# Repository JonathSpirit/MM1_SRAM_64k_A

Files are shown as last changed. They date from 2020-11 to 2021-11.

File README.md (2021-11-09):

# MM1_SRAM_64k_A

Copyright (C) 2020 Guillaume Guillet\
Licensed under CERN-OHL-W v2 or later

<table border="0px">
<tr>
<td>
This source describes Open Hardware and is licensed under the CERN-OHL-W v2 or later.
</td>
</tr>
<tr>
<td>
You may redistribute and modify this documentation and make products
using it under the terms of the CERN-OHL-W v2 (https:/cern.ch/cern-ohl).
This documentation is distributed WITHOUT ANY EXPRESS OR IMPLIED
WARRANTY, INCLUDING OF MERCHANTABILITY, SATISFACTORY QUALITY
AND FITNESS FOR A PARTICULAR PURPOSE. Please see the CERN-OHL-W v2
for applicable conditions.
</td>
</tr>
</table>

Made with [Kicad](https://kicad.org/)

## Description
A SRAM card with 64kBytes of capacity and compatible with [MM1 standard](https://github.com/JonathSpirit/GComputer_standard).

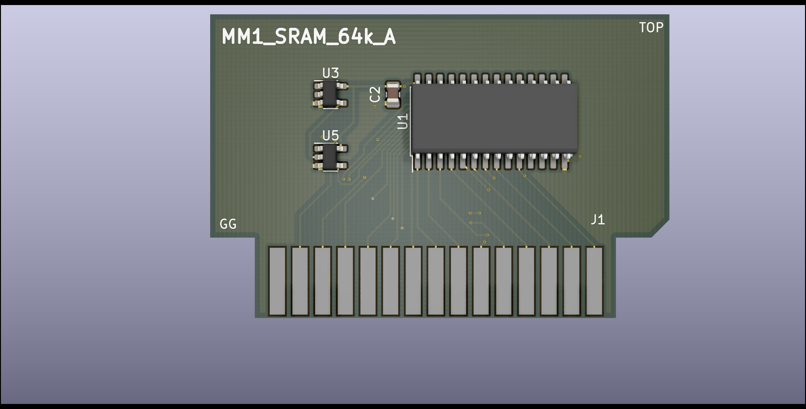
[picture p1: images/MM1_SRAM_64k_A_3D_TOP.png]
MM1_SRAM_64k_A_3D_TOP_image
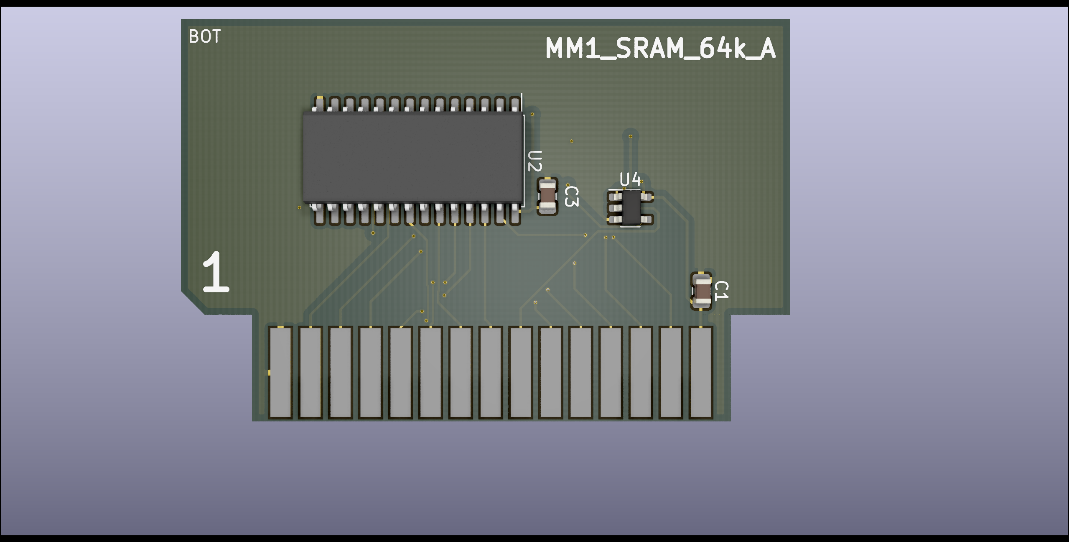
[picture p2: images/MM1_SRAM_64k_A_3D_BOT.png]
MM1_SRAM_64k_A_3D_BOT_image
 

## Status

Version :
> MM1_SRAM_64k_A revision 1

Status :
> Not tested !

Known issues :
> (Empty)

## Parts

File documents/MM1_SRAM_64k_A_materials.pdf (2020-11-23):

1

MM1_SRAM_64k_A_materials.fods

MM1_SRAM_64k_A | R1
Author : Guillaume Guillet | Revision 1 | Licensed under CERN-OHL-W v2 or later
Type | Value | Q | References | Package | Manufacturer | Store | Store ID | Unit price* | Price
C | 100nF | 3 | C1 to C3 | C_0805_2012Metric | KEMET | Mouser | 80-C0805C104K3R | 0.219 | 0.657
U | IS61LV256AL-10JL | 2 | U1, U2 | SOJ-28_P1.27mm | ISSI | Mouser | 870-61LV256AL10JLITR | 1.07 | 2.14
| 74AHC1G32 | 2 | U4, U5 | SOT-23-5 | Texas Instruments | Mouser | 595-SN74AHC1G32DBVR | 0.266 | 0.532
| 74AHC1G04 | 1 | U3 | SOT-23-5 | Texas Instruments | Mouser | 595-SN74AHC1G04DBVR | 0.266 | 0.266
- | PCB | 1 | | | G.Guillet | - | | | 0
Total price : | 3.595
*Depend of the quantity | Price is in CHF

# Project :

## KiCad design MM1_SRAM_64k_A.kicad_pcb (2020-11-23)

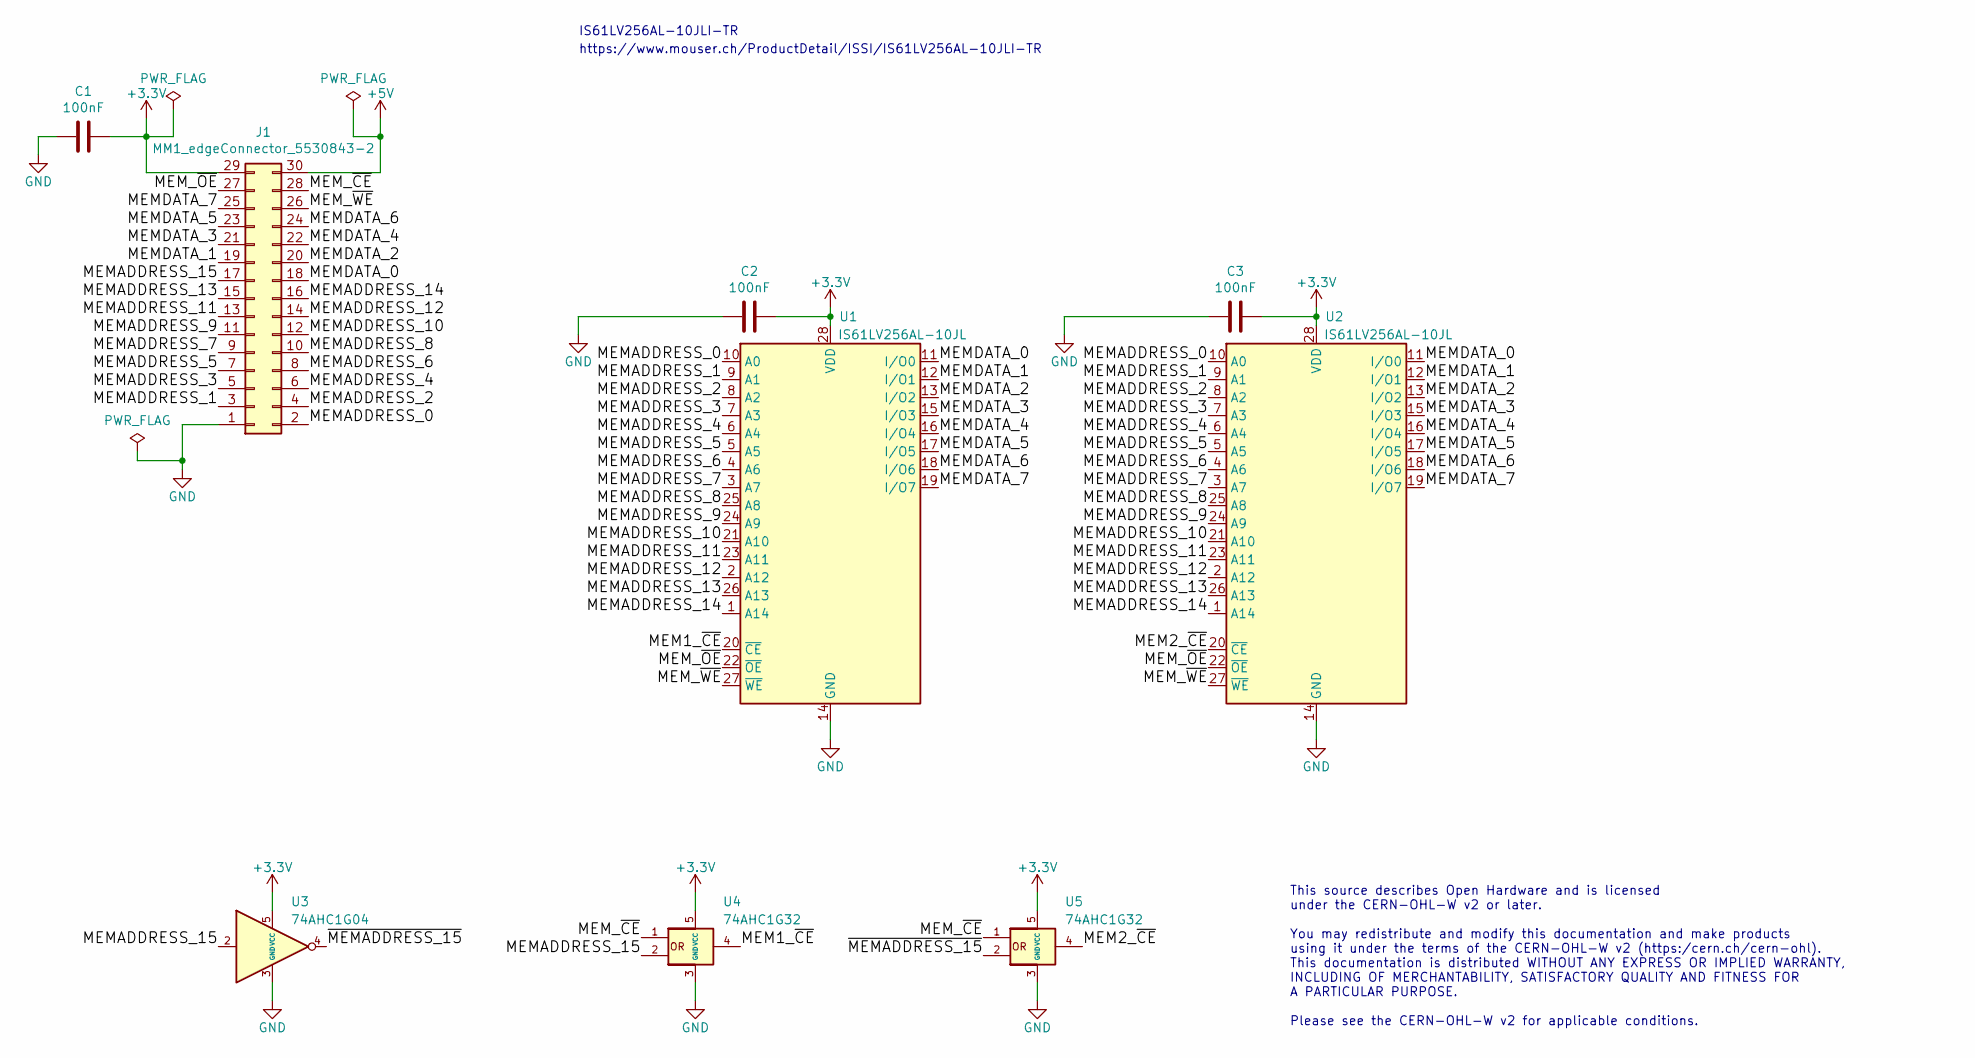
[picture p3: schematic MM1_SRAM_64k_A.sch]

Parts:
C1, C2, C3: 100nF; C_0805_2012Metric
J1: MM1_edgeConnector_5530843-2; 5530843-2_edge
U1, U2: IS61LV256AL-10JL; SOJ-28_P1.27mm
U3: 74AHC1G04; SOT-23-5
U4, U5: 74AHC1G32; SOT-23-5

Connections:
+3V3: C1.2, C2.1, C3.1, J1.29, U1.28 (VDD), U2.28 (VDD), U3.5 (VCC), U4.5 (VCC), U5.5 (VCC)
+5V: J1.30
/MEM1_~CE: U1.20 (~CE), U4.4
/MEM2_~CE: U2.20 (~CE), U5.4
/MEMADDRESS_0: J1.2, U1.10 (A0), U2.10 (A0)
/MEMADDRESS_1: J1.3, U1.9 (A1), U2.9 (A1)
/MEMADDRESS_2: J1.4, U1.8 (A2), U2.8 (A2)
/MEMADDRESS_3: J1.5, U1.7 (A3), U2.7 (A3)
/MEMADDRESS_4: J1.6, U1.6 (A4), U2.6 (A4)
/MEMADDRESS_5: J1.7, U1.5 (A5), U2.5 (A5)
/MEMADDRESS_6: J1.8, U1.4 (A6), U2.4 (A6)
/MEMADDRESS_7: J1.9, U1.3 (A7), U2.3 (A7)
/MEMADDRESS_8: J1.10, U1.25 (A8), U2.25 (A8)
/MEMADDRESS_9: J1.11, U1.24 (A9), U2.24 (A9)
/MEMADDRESS_10: J1.12, U1.21 (A10), U2.21 (A10)
/MEMADDRESS_11: J1.13, U1.23 (A11), U2.23 (A11)
/MEMADDRESS_12: J1.14, U1.2 (A12), U2.2 (A12)
/MEMADDRESS_13: J1.15, U1.26 (A13), U2.26 (A13)
/MEMADDRESS_14: J1.16, U1.1 (A14), U2.1 (A14)
/MEMADDRESS_15: J1.17, U3.2, U4.2
/MEMDATA_0: J1.18, U1.11 (I/O0), U2.11 (I/O0)
/MEMDATA_1: J1.19, U1.12 (I/O1), U2.12 (I/O1)
/MEMDATA_2: J1.20, U1.13 (I/O2), U2.13 (I/O2)
/MEMDATA_3: J1.21, U1.15 (I/O3), U2.15 (I/O3)
/MEMDATA_4: J1.22, U1.16 (I/O4), U2.16 (I/O4)
/MEMDATA_5: J1.23, U1.17 (I/O5), U2.17 (I/O5)
/MEMDATA_6: J1.24, U1.18 (I/O6), U2.18 (I/O6)
/MEMDATA_7: J1.25, U1.19 (I/O7), U2.19 (I/O7)
/MEM_~CE: J1.28, U4.1, U5.1
/MEM_~OE: J1.27, U1.22 (~OE), U2.22 (~OE)
/MEM_~WE: J1.26, U1.27 (~WE), U2.27 (~WE)
/~MEMADDRESS_15: U3.4, U5.2
GND: C1.1, C2.2, C3.2, J1.1, U1.14 (GND), U2.14 (GND), U3.3 (GND), U4.3 (GND), U5.3 (GND)

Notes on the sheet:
IS61LV256AL-10JLI-TR
https://www.mouser.ch/ProductDetail/ISSI/IS61LV256AL-10JLI-TR
This source describes Open Hardware and is licensed under the CERN-OHL-W v2 or later. You may redistribute and modify this documentation and make products using it under the terms of the CERN-OHL-W v2 (https:/cern.ch/cern-ohl). This documentation is distributed WITHOUT ANY EXPRESS OR IMPLIED WARRAN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

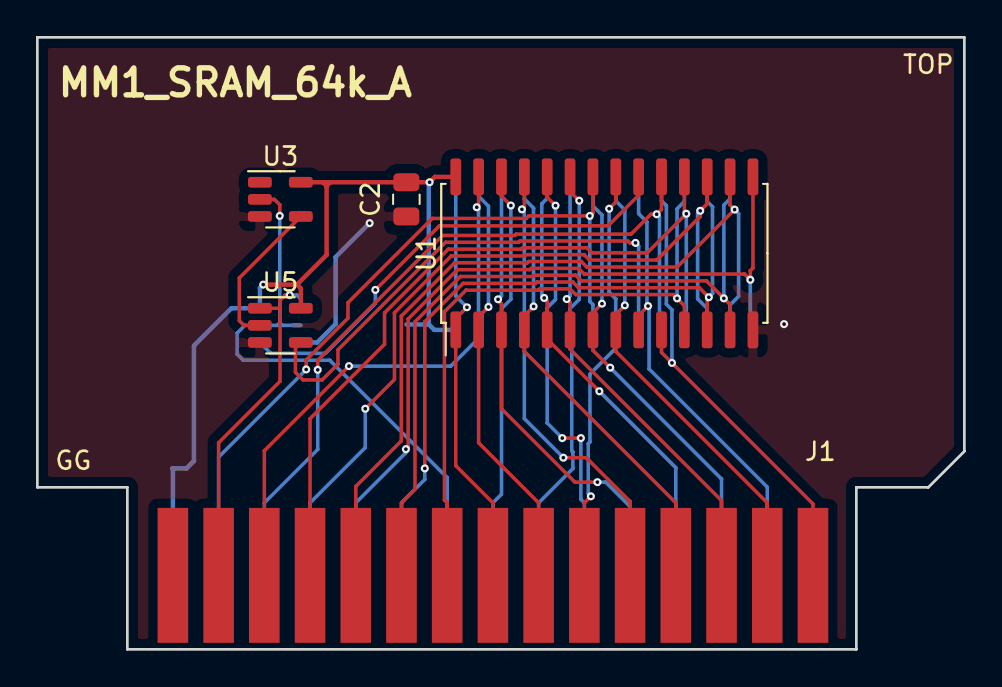
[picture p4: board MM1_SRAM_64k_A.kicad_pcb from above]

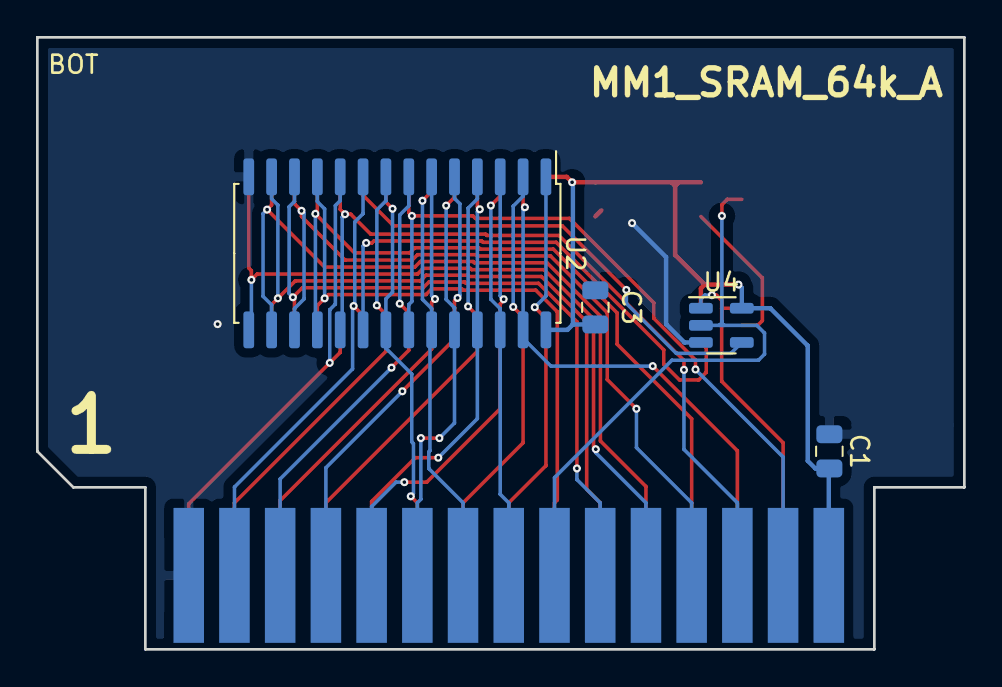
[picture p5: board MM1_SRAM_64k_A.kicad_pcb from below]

Board: 2 copper layers, 51.5 x 34.0 mm, 9 parts (4 on the bottom side), 32 nets.

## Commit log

2020-11-20 initial push
    [MM1_SRAM_64k_A.kicad_pcb, MM1_SRAM_64k_A.sch]
2020-11-23 custom SOJ-28 footprint and gerbert file
    [MM1_SRAM_64k_A-B_Cu.gbr, MM1_SRAM_64k_A-B_Mask.gbr, MM1_SRAM_64k_A-B_SilkS.gbr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]
2021-11-08 Update README.md
    https://forum.kicad.info/t/warning-avoid-all-links-to-kicad-pcb-org-use-kicad-org/31521

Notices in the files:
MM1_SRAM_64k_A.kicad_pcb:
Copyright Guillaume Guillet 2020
